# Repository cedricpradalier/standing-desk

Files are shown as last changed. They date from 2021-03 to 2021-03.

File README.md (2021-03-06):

# Standing Desk

This github project provides the design document for a cantilevered computer support for a standing desk. It is organised in 3 parts:
* doc: contains a PDF describing the mathematics behind the standing desk design: https://github.com/cedricpradalier/standing-desk/blob/main/doc/support.pdf

* cad: provides an OpenSCAD design file to generate a 3D model of the design, prepare 3D prints or get the dimensions for other design parameters (the maths are the one described in the PDF, so there is no absolute need fro the OpenSCAD file).

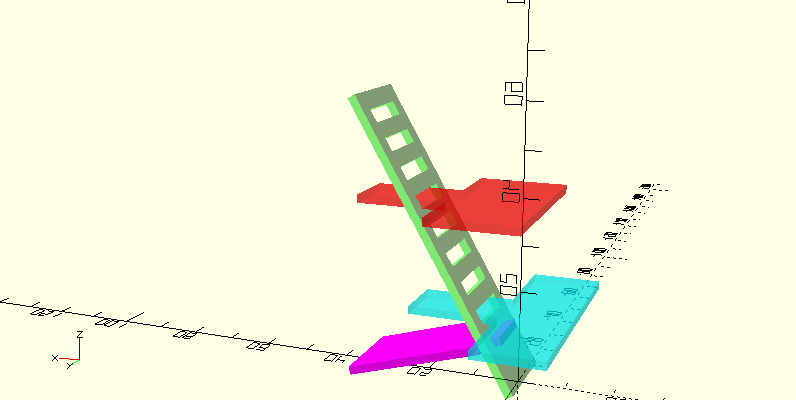
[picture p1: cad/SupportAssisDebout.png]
CAD example


* pics: example of pictures of the standing desk

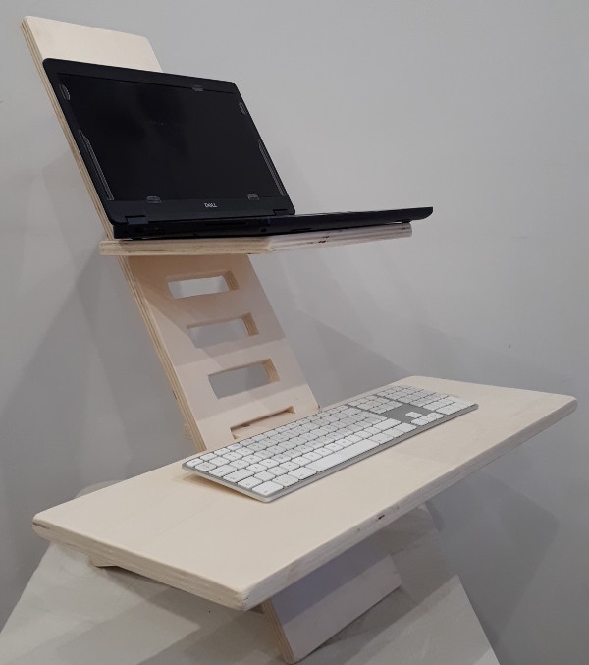
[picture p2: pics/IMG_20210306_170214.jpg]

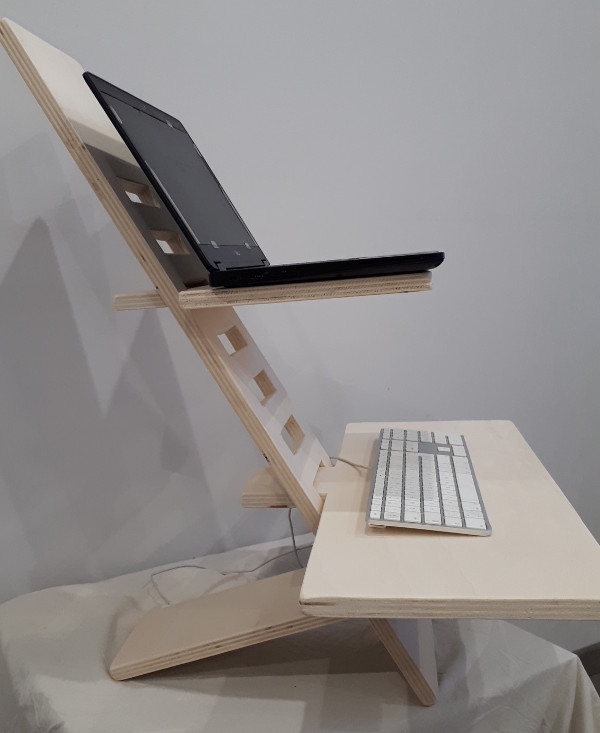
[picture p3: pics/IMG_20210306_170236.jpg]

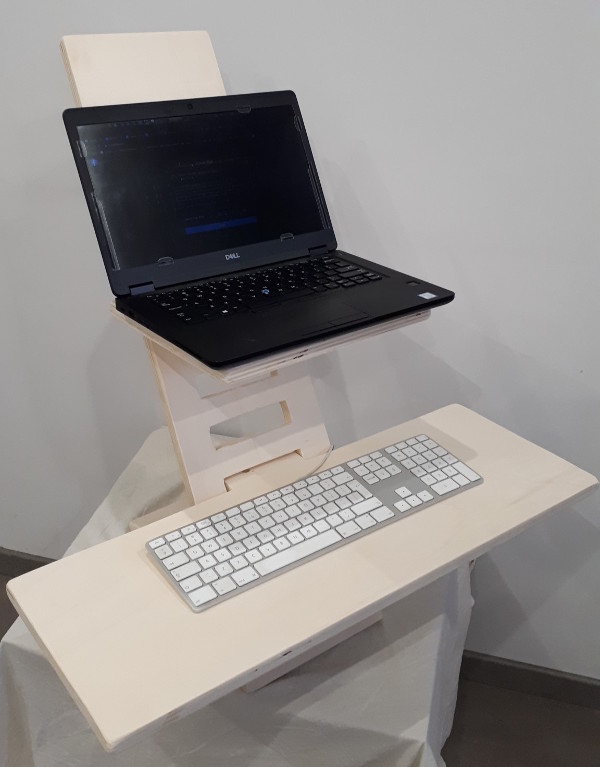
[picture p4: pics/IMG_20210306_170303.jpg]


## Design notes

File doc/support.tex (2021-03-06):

\documentclass{article}
\usepackage{a4wide}
\usepackage{graphicx}

\title{Design principles for standing desk computer support}
\author{Cedric Pradalier}

\begin{document}
\maketitle

\section{Principle}
\begin{center}
    
\end{center}
The core design parameters are the angle $\alpha$ of the ladder, and the thickness $T$ of the wood.

\section{Width of the support tablet}
\begin{center}
    
\end{center}
The support tablet needs to be horizontal, which happens if the insertion slot defined by the polygon ABCDEF has the right width.

If the tablet is horizontal, we have
$$DE = \frac{T}{\cos\alpha}$$
Which means that:
$$EF = T \tan\alpha$$
So
\begin{equation}
    \label{eq:tablet-slot}
    DF = T\left(\frac{1}{\cos \alpha} + \frac{\sin \alpha}{\cos\alpha}\right) = 
    T \left(\frac{1 + \sin\alpha}{\cos \alpha}\right)
\end{equation}

\section{Design of the support leg}
\begin{center}
    
\end{center}
Let us first assume that the length of the ladder is $L$. For stability, we assume that $EF = L \sin\alpha$. We now define $p_{leg} = HA$, which is a fourth design parameter.

In order to compute the angle $\beta$, we use the fact that:
$$
\tan \beta = \frac{AA'}{A'F}
$$
We start with $AA' = JG + KA$:
$$
JG = A'G \cos \alpha = p_{leg} \cos \alpha
$$
and 
$$
KA = T \sin \alpha
$$
Then $A'F = EF - (EJ - JA')$:
$$
EJ=p_{leg} \sin \alpha
$$
and 
$$
JA' = GK = T \cos\alpha
$$
Finally:
$$
\beta = \arctan \frac{p_{leg} \cos \alpha + T \sin \alpha}{L\sin\alpha - (p_{leg} \sin \alpha - T \cos \alpha)}
$$
Knowing $\alpha$ and $\beta$, we have:
\begin{equation}
    \label{eq:leg-slot}
    GC =  T \left(\frac{1 + \sin\left(\alpha-\beta\right)}{\cos\left(\alpha-\beta\right)}\right)
\end{equation}
Same formula as eq.~\ref{eq:tablet-slot}. $\alpha-\beta=0$ corresponds to a leg orthogonal to the ladder. 

\section{Insert length}
\begin{center}
    
\end{center}
The final point is compute to minimal length of the part of the leg inserted into the ladder. The leg will be inserted until the stopper is on C. At this time, the leg still needs to be in contact in A.
We have:
$$
AC = \textrm{hypot}(T,GC)
$$
Also
$$
\sin \gamma = \frac{T}{AC}
$$
Hence:
\begin{equation}
\label{eq:insert}
PC = AC \cos \gamma
\end{equation}
gives us the minimal length of the insert section. 

This also gives us the length $L_{leg}$ of the part of the leg {\bf not} inserted in the ladder:
\begin{equation}
    \label{eq:leglength}
    L_{leg} = \frac{AA'}{\sin\beta} - PC = \frac{p_{leg}\cos\alpha + T \sin \alpha}{\sin \beta} - AC\cos\gamma
\end{equation}

\section{Design example}

The final design, for an angle $\alpha$ of 60 degrees, wood thickness of $T$  of 18mm, $p_{leg}$ of 100mm  is shown here:
\begin{center}
    
\end{center}
The resulting assembly is shown here:
\begin{center}
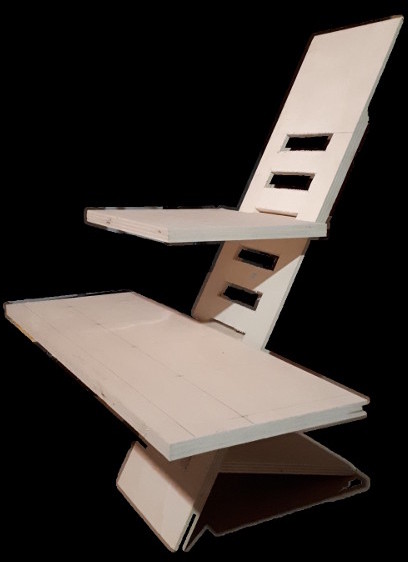
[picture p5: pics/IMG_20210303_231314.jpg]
    
    \hfill
    
\end{center}

\end{document}

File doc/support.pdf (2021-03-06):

# Design principles for standing desk computer support

Cedric Pradalier

March 6, 2021

## 1 Principle

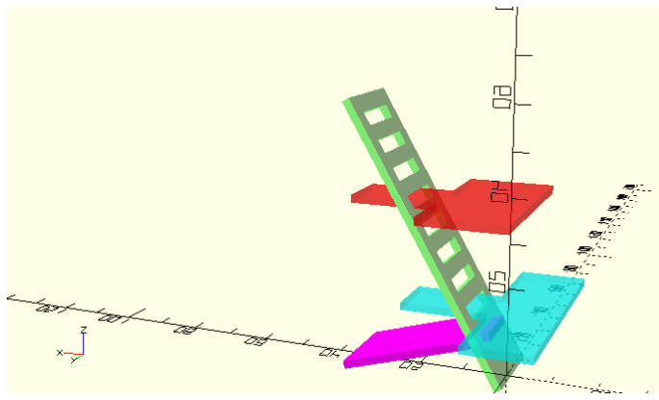
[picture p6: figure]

The core design parameters are the angle α of the ladder, and the thickness T of the wood.

## 2 Width of the support tablet

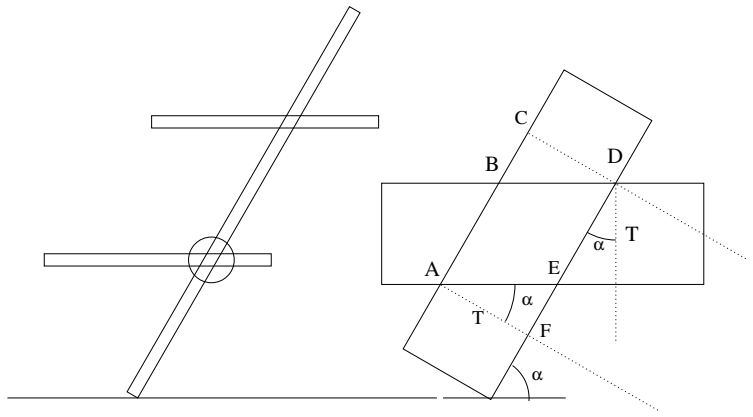
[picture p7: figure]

The support tablet needs to be horizontal, which happens if the insertion slot defined by the polygon ABCDEF has the right width.
If the tablet is horizontal, we have

DE =

T
cos α
Which means that:
EF = T tan α

So
DF = T
1
cos α

+

sin α
cos α
= T
1 + sin α
cos α
(1)

## 3 Design of the support leg

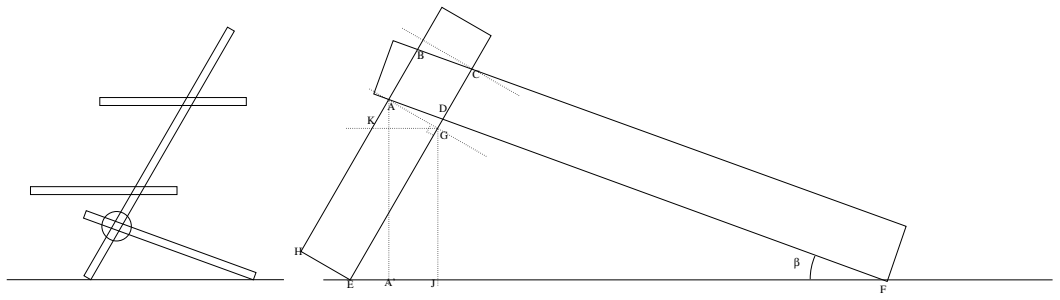
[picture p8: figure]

Let us first assume that the length of the ladder is L. For stability, we assume that EF = Lsin α. We now define pleg = HA, which is a fourth design parameter.
In order to compute the angle β, we use the fact that:

tan β =

AA⁰
A⁰F

We start with AA⁰ = JG + KA:

JG = A

0G cos α = pleg cos α

and
KA = T sin α

Then A⁰F = EF − (EJ − JA⁰
):
EJ = pleg sin α

and
JA⁰ = GK = T cos α

Finally:

β = arctan

pleg cos α + T sin α
Lsin α − (pleg sin α − T cos α)

Knowing α and β, we have:

GC = T

1 + sin (α − β)
cos (α − β)
(2)

Same formula as eq. 1. α − β = 0 corresponds to a leg orthogonal to the ladder.

## 4 Insert length

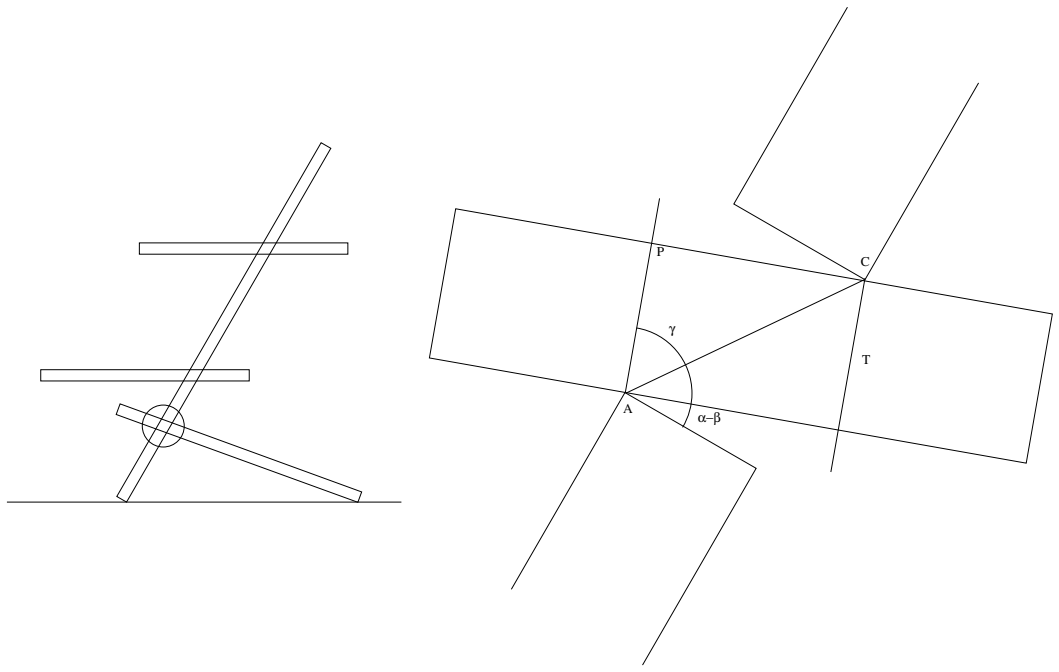
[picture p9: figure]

The final point is compute to minimal length of the part of the leg inserted into the ladder. The leg will be inserted until the stopper is on C. At this time, the leg still needs to be in contact in
A. We have:
AC = hypot(T, GC)

Also
sin γ =

T
AC
Hence:
P C = AC cos γ | (3)

gives us the minimal length of the insert section.
This also gives us the length Lleg of the part of the leg not inserted in the ladder:

Lleg =

AA⁰
sin β

− P C =

pleg cos α + T sin α
sin β
− AC cos γ | (4)

## 5 Design example

The final design, for an angle α of 60 degrees, wood thickness of T of 18mm, pleg of 100mm is shown here:

# Standing desk: 60 degrees

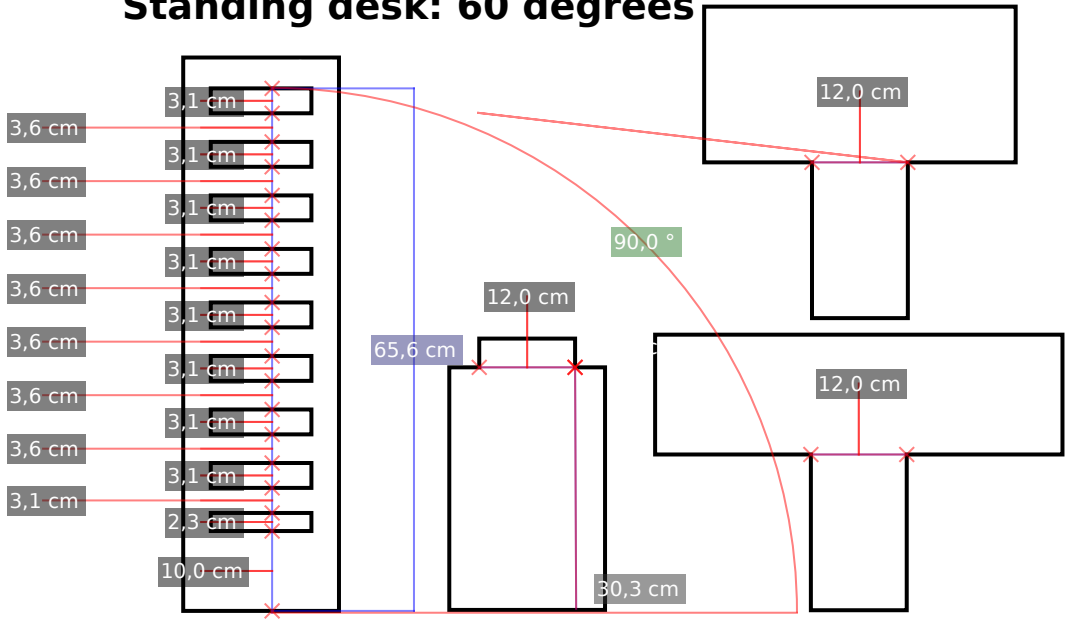
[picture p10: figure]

The resulting assembly is shown here:

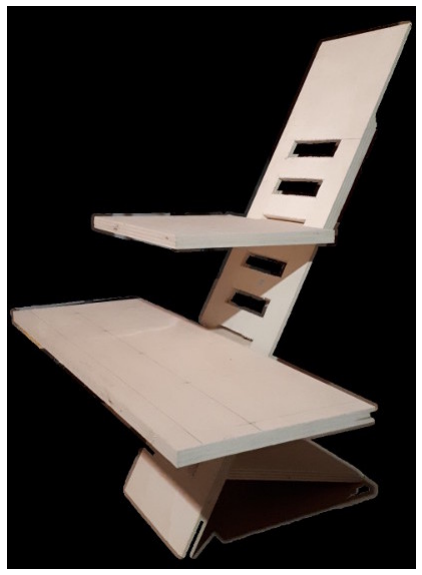
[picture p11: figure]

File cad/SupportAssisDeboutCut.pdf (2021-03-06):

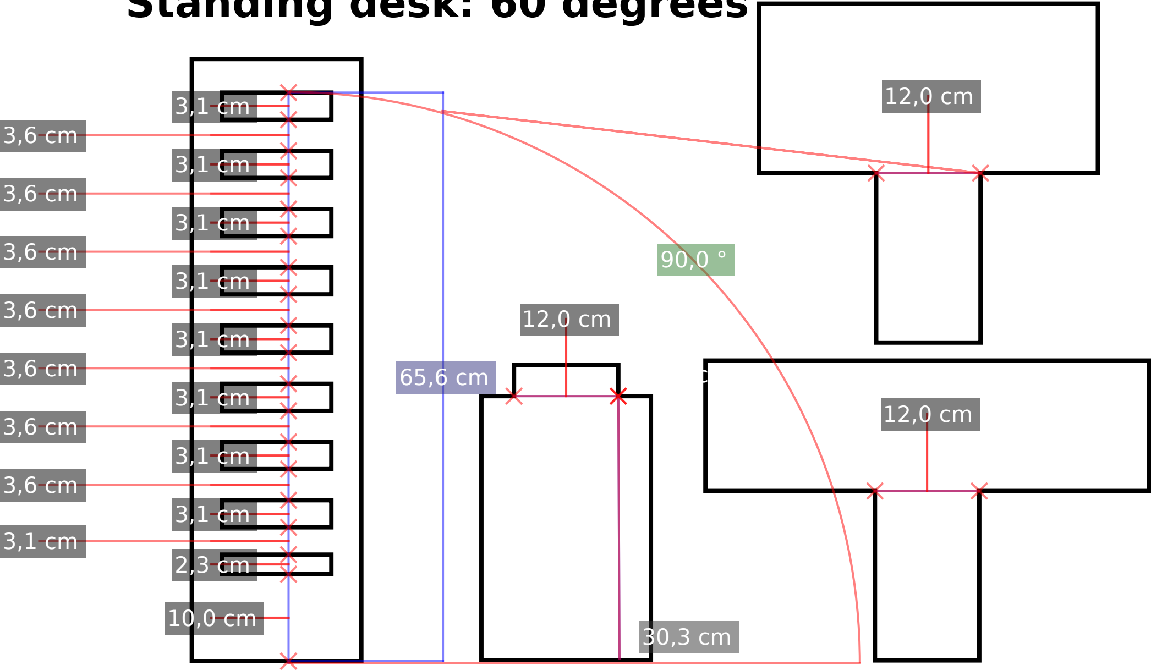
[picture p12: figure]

# Standing desk: 60 degrees

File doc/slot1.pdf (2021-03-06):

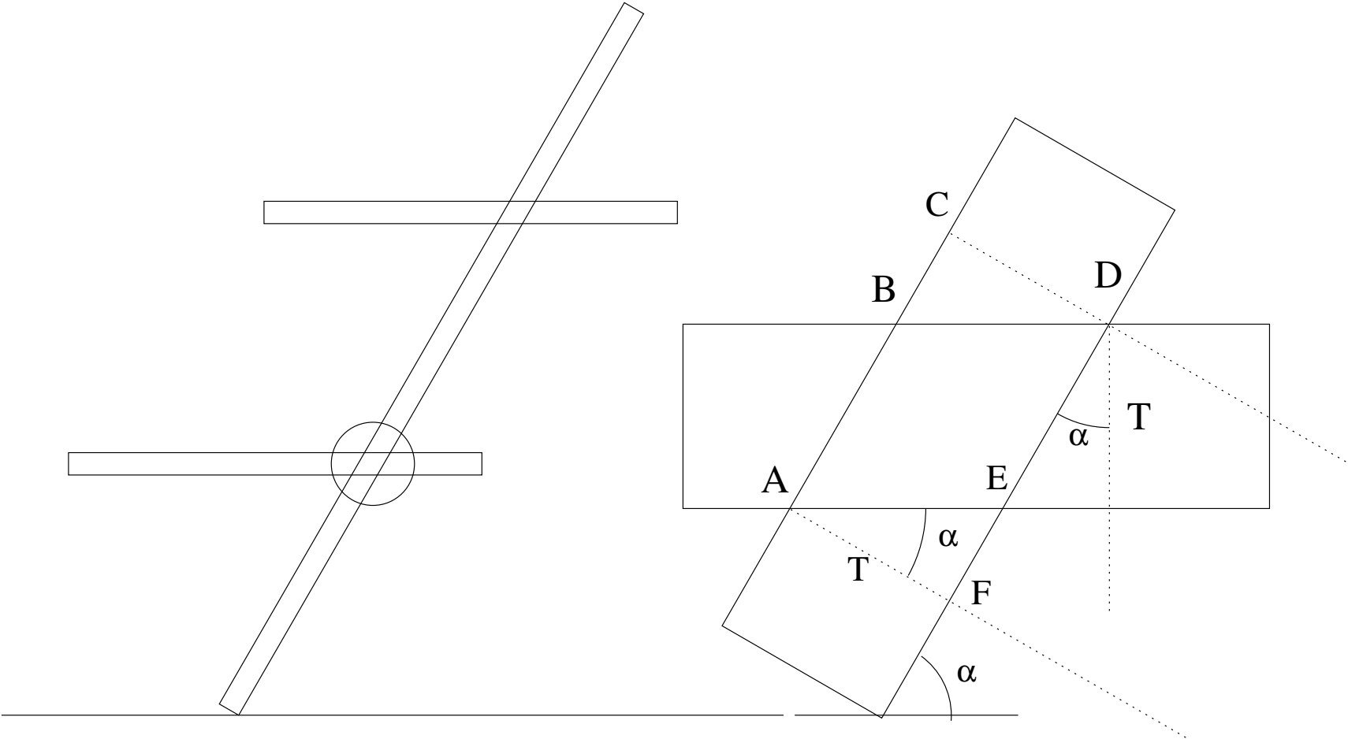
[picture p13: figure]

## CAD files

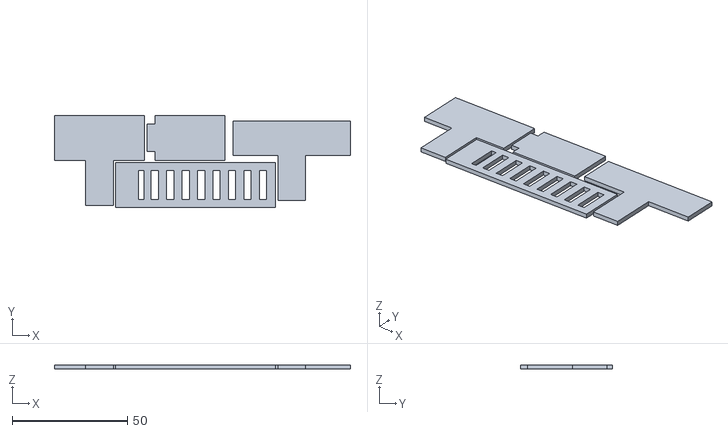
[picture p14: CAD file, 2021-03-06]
cad/SupportAssisDeboutCut.stl
128.3 x 40.0 x 1.80

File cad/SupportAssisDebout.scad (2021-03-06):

alpha=30;
h=60    ;
W1=12;
thickness=1.8;
L=h/cos(alpha);
echo("L");echo(L);
L2b=2*thickness;
W=19.5;
slotoffset=2;
slotspace=6.7;
cutline=1;

    // Orthogonal leg: 
//    pleg=L*sin(alpha)*sin(alpha);
//    L2a=L2b + L*sin(alpha)*cos(alpha);
//    Eleg=thickness;

    // generic leg
    pleg=10;
    hleg=pleg*cos(alpha) + thickness*sin(alpha);
    Cleg=L*sin(alpha) - (pleg*sin(alpha)-thickness*cos(alpha));
    alphaleg=atan(hleg/Cleg);
    //echo(alphaleg);
    Eleg=thickness*(1+sin(alpha-alphaleg))/cos(alpha-alphaleg);
    echo("Eleg");
    echo(Eleg);
    d=sqrt(Eleg*Eleg+thickness*thickness);
    L2a=L2b + hleg/sin(alphaleg) - d * sin(acos(thickness/d));
    echo("Leg length");
    echo(L2a-L2b);


E1=thickness*(1 + sin(alpha))/cos(alpha);
echo("E1");
echo(E1);

L3=15; // keyboard
L4=20; // screen

L3a=W;
L3b=L3a+L3;
Wkeyboard=60;
echo("Keyboard");
echo([Wkeyboard,L3b]);

L4a=W1;
L4b=L4a+L4;
Wscreen=30;
echo("Screen");
echo([Wscreen,L4b]);
slotscreen=5;
hscreen = (slotoffset + slotspace*slotscreen)*cos(alpha)
    + thickness*sin(alpha);

slotkeyboard=2;
hkeyboard = (slotoffset + slotspace*slotkeyboard)*cos(alpha)
    + thickness*sin(alpha);

echo("Length");
echo(L+W1+W1+(Wscreen-W1)/2+(Wkeyboard-W1)/2+2*cutline);
echo("Width");
echo(L4b+cutline);

// projection(cut=false) translate([0,0,50]) 
{
//Mounting
rotate([0,-(90-alpha),0]) 
//Cutting
//translate([-L4a,(W+W1)/2+2,0])
color("#00FF00",0.5)
difference() {
    linear_extrude(height=thickness) {
        polygon(points=[[0,-W/2],[L,-W/2],[L,W/2],[0,W/2]]);
    }
    union() {
        echo("p");
        for (i=[2:9]) {
            translate([0,0,-1]) linear_extrude(height=thickness+2) {
                p=slotoffset+slotspace*i;
                echo([p,p+E1]);
                polygon(points=[[p,-1.05*W1/2],[p+E1,-1.05*W1/2],[p+E1,1.05*W1/2],[p,1.05*W1/2]]);
            }
        }
        translate([0,0,-1]) linear_extrude(height=thickness+2) {
            polygon(points=[[pleg,-1.05*W1/2],[pleg+Eleg,-1.05*W1/2],[pleg+Eleg,1.05*W1/2],[pleg,1.05*W1/2]]);
        }
    }
}

// Cutting
//translate([Wscreen/2-W1/2,(W+W)/2+cutline,0])
color("#FF00FF")
// Mounting
translate([(L2a-L2b)*cos(alphaleg)+(pleg+Eleg)*sin(alpha)-thickness*sin(alphaleg),0,0])
rotate([0,alphaleg,0])
translate([-L2a,0,0])
linear_extrude(height=thickness) {
    polygon(points=[[0,-W1/2],[L2b,-W1/2],[L2b,-W/2],
           [L2a,-W/2],[L2a,W/2],[L2b,W/2],[L2b,W1/2],[0,W1/2]]);
}

// Mounting
translate([hscreen*tan(alpha)+0.8*L4a,0,hscreen])
rotate([0,0,180])
// Cutting
//translate([-cutline-W1/2,cutline-W/2,0])
//rotate([0,0,90])
color("#FF0000",0.5) 
linear_extrude(height=thickness) {
    polygon(points=[[0,-W1/2],[L4a,-W1/2],[L4a,-Wscreen/2],
           [L4b,-Wscreen/2],[L4b,Wscreen/2],
            [L4a,Wscreen/2],[L4a,W1/2],[0,W1/2]]);
}


// Mounting
translate([hkeyboard*tan(alpha)+0.5*L3a,0,hkeyboard])
rotate([0,0,180])
// Cutting
//translate([cutline+L+W1/2,cutline-W/2,0])
//rotate([0,0,90])
//translate([2,0,0])
color("#00FFFF",0.5) 
linear_extrude(height=thickness) {
    polygon(points=[[0,-W1/2],[L3a,-W1/2],[L3a,-Wkeyboard/2],
           [L3b,-Wkeyboard/2],[L3b,Wkeyboard/2],
            [L3a,Wkeyboard/2],[L3a,W1/2],[0,W1/2]]);
}
}

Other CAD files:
cad/SupportAssisDeboutCut.scad
